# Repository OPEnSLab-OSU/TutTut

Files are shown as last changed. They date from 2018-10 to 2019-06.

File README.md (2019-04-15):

# TutTut
Tut-Tut, the IoT Raindrop Detector, is a project under the domain of the OPEnS (Openly Published Environment Sensing) Lab at Oregon State University. 
Tut-Tut will be able to detect a raindrop of any size, get an idea of the drop's mass from the intensity at which it falls, and detect the frequency of raindrops. 
After Tut-Tut gathers this data, it will be able to wirelessly transmit the information to a central server and communicate it to other IoT devices around Oregon State University.
The detector will periodically wake up to check for rain and will stay awake as long as rain is detected within two minutes. If it does not detect raindrops within two minutes, it will go back to sleep.
As a stretch goal, we will design an online mobile application to which the physical device will transmit information about the raindrops.
If this stretch goal is not met, then the data will be stored in a Google Sheet.

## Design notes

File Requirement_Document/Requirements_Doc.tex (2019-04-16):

%\documentclass[10pt,a4paper]{article}
\documentclass[letterpaper,10pt,draftclsnofoot,onecolumn]{article}
\usepackage[letterpaper, margin=.75in]{geometry}

\usepackage{hyperref}
\usepackage{listings}
\usepackage{wasysym}
\usepackage{graphicx}

\graphicspath{ {./images/}}

\hypersetup{
	colorlinks,
	citecolor=black,
	filecolor=black,
	linkcolor=black,
	urlcolor=black
}

\begin{document}
\begin{titlepage}
\vspace*{\fill}
\begin{center}
{\Large Tut-Tut, The IoT Rain Fall Detector Requirements Document}
\\[0.3cm]

{\large CS 461 - Fall 2018}
\\[0.3cm]

{\large Jonathan Rohr}
\\[0.3cm]

{\large Michael Gillett}
\\[0.3cm]

{\large Shreyans Khunteta}
\\[0.3cm]

{\large October 23, 2018}
\\[1cm]

{\Large Abstract}
\end{center}
Tut-Tut, the IoT Raindrop Detector, is a project under the domain of the OPEnS (Openly Published Environment Sensing) Lab at Oregon State University. Tut-Tut will be able to detect a raindrop of any size, get an idea of the drop's mass from the intensity at which it falls, and detect the frequency of raindrops. After Tut-Tut gathers this data, it will be able to wirelessly transmit the information to a central server and communicate it to other IoT devices around Oregon State University. The detector will periodically wake up to check for rain and will stay awake as long as rain is detected within two minutes. If it does not detect raindrops within two minutes, it will go back to sleep. As a stretch goal, we will design an online mobile application to which the physical device will transmit information about the raindrops. If this stretch goal is not met, then the data will be stored in a Google Sheet.
\vspace*{\fill}
\end{titlepage}

\section{Introduction}
In this document we will be outlining the requirements of Tut-Tut, the Internet of Things (IoT) Rainfall Detector. Requirements are as per requested by Chet Udell and the OPEnS Lab located at Oregon State University.

\subsection{Purpose}
This document intends to guide development of Tut-Tut over the course of 7 months. It will go through changes in the duration of the project as new information makes itself clear.

\begin{enumerate}
    \item \textbf{Draft:}  The first draft is written by the development team after requirements have been outlined by their client. 
    \item \textbf{Proposal:} The drafted document will be passed along to all other parties involved, including the client, OPEnS lab team, and course professors, who will evaluate the requirements outlines and request changes where necessary.
    \item \textbf{Approved:} The document is considered approved when it is accepted by all parties. Following this, the development team can begin implementing their technology using the document as a guide.
\end{enumerate}

\subsection{Target Audience}
This product is designed to accommodate any person(s) who may want to know about rainfall metrics in their area. The sensor will provide real-time information about the relative intensity of the rain based on the impacts of the drops and how frequently they are falling. These metrics could be used by meteorologist as a way to show more detailed information about the rain in the local area. Furthermore, the Tut-Tut Rainfall Detector will link into the OPEnS lab's larger ecosystem of environmental devices and sensors, known as Loom.

\subsection{Project Scope}
%describes the expectations of the product if it were to hit the market, e.g. what must be done to deliver the working product
When the Tut-Tut is finished at the end of the development period, it will be expected to perform three major tasks and one task that will be implemented if there is time. First, it will need to be able to translate vibrations from rainfall using its on-board vibration sensors. Second, it will transmit the collected data to an internet hub where it is subsequently uploaded to Google Sheets in real-time. Third, it must be integrated into the existing OPEnS Lab's ecosystem of sensors and devices called Loom. Finally, if time permits, a browser UI will be used to communicate the Tut-Tut data in an easy to understand way.

\subsection{Business Case for the Product}
%Why do we need this product in the world?
From a business standpoint, this product could deliver an understanding of the rainfall for different areas in the form of a comprehensive map. If the Tut-Tut rainfall detector were to be placed around the country, it could tell you about the type of rain that falls in a given region. Rain on the East Coast might be more of a mist, while the rain in Oregon falls quickly and intense. Tut-Tut would give us the data to show those claims in the form of data it gathers.

\subsection{Overview}
%Summary of the requirements, a general idea
In order to create this device, we will need to program our microcontroller, test vibration sensors, design and 3D print the enclosure, store all code in a github repository, integrate it into Loom, and if possible, create a browser UI as a way to highlight useful information in the spreadsheets.

\section{General Description}
%SECTION TWO, THE REAL DEAL
%Non-technical description, easily read in laymans terms
The IoT raindrop detector will be used to record the amount of rainfall in a particular area. This can be particularly useful in agricultural farming, as this means farmers will know exactly how much rainfall their crops are getting and this way the farmers know how much rainfall they have to provide their crops. 

\subsection{Product Perspective}
%Why are we developing this product?
The thought behind this product's development is that the Loom network managed by Oregon State's OPEnS lab lacks a device that provides more specific details about rainfall. When this product is finished and integrated into their network, the findings might be significant enough to allow Tut-Tut to be available to the public. Even if the data turns out to only be significant to a small population of people, we still will have helped out those individuals, and the Loom network will have a new integration that could inspire similar devices.

\subsection{Product Functions}
%What does it do? Main functions
The main functions of this raindrop detector are that it can detect raindrop impacts, frequency rate and relative intensity of the rainfall based on the raindrop impacts. It also will link up with the network of IoT devices maintained by the OPEnS lab. It will also upload its data to a central server where the information can be viewed in a Google Sheet. It will need to go to sleep while it is not raining so that the battery does not drain.

\subsection{End User Characteristics}
%What would someone using the final product expect from it? Who would that person be? Do they need a technical background or can they use it right away with no prior knowledge of its development?
If we develop the mobile application (which is our stretch goal), the end user can be anyone capable of using the interface. We plan to have a user-friendly interface where anyone can use the application to see the performance metrics of the IoT device.
\newline
If we don't meet the stretch goal, the end user will be anyone able to use the Loom network of IoT devices around Oregon State. This project will be then used next year for another Capstone team to build off of.

\subsection{Constraints}
%Any constraints that might get in the way of development?
One of the biggest constraints of the project is time. All the members of this team are seniors at Oregon State. This is a project we are doing on the side after our classes and jobs, so we have to cut time out of our schedules to work on it. We have created a Standards document which we have all agreed to to deal with this problem in advance.
\newline
But more than that a constraint is Professor Udell's time. He is extremely busy so if we have questions, getting a meeting can be difficult. We have set up a meeting at 10 am every Thursday to circumvent this problem as well.
\newline
Another constraint is equipment. We will be using OPEnS lab equipment for this entire project. We are also totally reliant on them for everything so if some equipment breaks or proves ineffective, we will wait for the lab to get us new equipment.
\newline
Another constraint is expertise. We're students who are doing a project of this magnitude for the first time. We will be learning a lot during this experience but there is absolutely going to be a learning curve. It will take time for us to get up to speed.

\subsection{Assumptions and Dependencies}
%Dependencies (internet connection within range, battery or plug, etc) Assumptions (End User skills or prior knowledge)
Using this product effectively will require an internet connection and a power source. The Feather M0 microcontroller comes equipped with a Wi-Fi card, so anywhere on the university should be suitable enough for Tut-Tut. Using the device anywhere else must have a Wi-Fi signal within range. Another dependency is the power source. Because Tut-Tut is intended to be moved around, Tut-Tut should run on a battery. The type of battery we will use is undetermined, and will be figured out in the testing phase. Users should need no prior knowledge to configure and set up Tut-Tut.

\section{Specific Requirements}
This section of the document lists specific requirements for Tut-Tut. Requirements will be divided into three sections:
\begin{enumerate}
    \item \textbf{User Requirements: } These are requirements written from the point of view of the end users who will be using the product.
    \item \textbf{System Requirements: } These are the detailed specifications that the product's internal hardware will need to be capable of doing.
    \item \textbf{Interface Requirements: } These are the requirements about how the information gathered by the device will be presented 
\end{enumerate}

\subsection{User Requirements}
%Minimal, since the information will be understood by everyone
The user will, provided our stretch goal is met, be anyone. The information will be easily accessible and understandable. Even if our stretch goal isn't met, we will still display our data gathered in a Google Sheet that should be able to be understood by anyone.

\subsection{System Requirements}
%2x2 inch sensor capable of detecting even the most minute amounts of rain, wifi or network capabilities, able to be integrated with mesh network, waterproof
The system will be a 2x2 inch weather resistant sensing area capable of detecting even the most minute amounts of rain. It will have wi-fi or network capabilities and we will be able to integrate it easily with the IoT mesh network around the university. It will be able to detect the raindrop impacts, the frequency at which rain is falling, and the intensity at which it hits the detector. The device will also need to go to sleep while it is not raining to conserve battery. It will awaken when it can detect rain falling and will continue gathering data.

\subsection{Interface Requirements}
%needs to be accessible and give accurate or clear information. Perhaps in the form of a generated map visual, or a twitter bot.
The interface for the mobile application, if the stretch goal isn't met, will just be an Excel spreadsheet with all the data cleanly labelled. If the stretch goal is met, it will be a mobile application that can easily be navigated. The specifics of the application's appearance will be worked out, but it will be easy to look at and trivial for an inexperienced user to find all the information they are looking for.

\section{Gantt Chart}
%Chart outlining the timeline of this project. Term one is design, Term two is bulding, and Term 3 is testing. That's my only information


\newline

\bibliography{myref}
\bibliographystyle{ieeetr}

\end{document}t}

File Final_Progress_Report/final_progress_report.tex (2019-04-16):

%\documentclass[10pt,a4paper]{article}
\documentclass[letterpaper,10pt,draftclsnofoot,onecolumn]{article}
\usepackage[letterpaper, margin=.75in]{geometry}

\usepackage{hyperref}
\usepackage{listings}
\usepackage{wasysym}
\usepackage{graphicx}
\usepackage{float}

\graphicspath{ {./images/}}

\hypersetup{
	colorlinks,
	citecolor=black,
	filecolor=black,
	linkcolor=black,
	urlcolor=black
}

\input{arduinoLanguage.tex}

\begin{document}
\begin{titlepage}
\vspace*{\fill}
\begin{center}
{\Large Tut-Tut, The IoT Rainfall Detector Progress Report}
\\[0.3cm]

{\large Team 21}
\\[0.3cm]

{\large CS 461 - Fall 2018}
\\[0.3cm]

{\large Jonathan Rohr,}
{\large Shreyans Khunteta,}
{\large Michael Gillett}
\\[0.3cm]

{\large February 21st, 2019}
\\[1cm]

{\Large Abstract}
\end{center}

Tut-Tut, the IoT Raindrop Detector, is a project under the domain of the OPEnS (Openly Published Environment Sensing) Lab at Oregon State University. Tut-Tut will be able to detect a drop of any size, get an idea of the raindrop mass from the intensity at which it falls, and detect the frequency of raindrops. After Tut-Tut gathers this data, it will be able to wirelessly transmit the information to a central server and store it in a database. This document will explore multiple possible technologies that can be used to gather, transmit, and store our data.
\vspace*{\fill}
\end{titlepage}

\section{Project Purposes and Goals}
The purpose of Tut-Tut is to provide metrics for understanding the intensity of rainfall as it is happening. We plan on using our sensor to measure how forceful the impact of the raindrops are, and the microcontroller's built-in timer to record the duration between those drops.
\newline
With these two parameters, we will place each recorded drop on a scale between 0 and 100, 0 being no rain at all and 100 being torrential downpour, and provide a key with ranges describing the rain in more familiar terms. For example: 0-15 would represent a mist, 15-30 would represent a light rain (jacket recommended), 30-45 would represent a medium rain (umbrella recommended), all the way up to cataclysmic conditions. A rating of 100 should not be reasonably attainable on our scale, so that we can represent any recorded value somewhere on the spectrum. 
\newline
We were hoping to introduce a browser UI system to represent this data in a colorful map or Twitter feed, but this will likely be cut out due to time constraints. That browser UI will be left to a future Capstone team. Such a browser UI could potentially have appealing visuals along with the OSU logo that will render the information much easier to read. However, at the moment, we will just publish the results to a Google Sheets using PushingBox.
\newline
The ultimate end goal use of Tut-Tut will be to, for example, put in farmer's fields. Farmers will be able to see how much rain their crops are getting in specific areas and thus know exactly how much water they should give their crops. This will greatly aid in water conservation which has become a moral and practical necessity as the effects of climate change worsen.

\section{Current Progress}
We have chosen the MEMS sensor due to how sensitive it is relative to the accelerometer and the piezoelectric transducer. In addition we were able to build a quite functional rig that can detect raindrops and then have them neatly slide off the disk. Our MEMS sensor can detect the force of the impacts and we have code that gives us the average amplitude for a specific duration of time. That same duration is used to calculate the frequency that raindrops impact the sensing area. Our microcontroller enters low-power mode when the sensor hasn't detected a drop in one minute. A drop hitting the sensing area will trigger an interrupt that will wake up the microcontroller so data can be gathered again. Our data gets sent to a Google Sheet every two minutes using a Pushing Box API Scenario. Essentially, the data is used as URL arguments for a get request to Google Sheets. A script in our Google Sheet will recognize the format of the request and will add the data to the sheet.
\newline
\newline
We made some 3D prints of disks and our casing for the electronic components by using a software called Autodesk Fusion360 after an unsuccessful attempt in using AutoCAD Architecture. After realizing that AutoCAD Architecture was a bit of a nightmare to use, we switched over to Autodesk Fusion360 on the advice of Professor Chet Udell. We learned how to use Autodesk Netfabb to check the mesh to make sure there were no errors in it, and then we used Cura Lulzbot to compile our meshes into a file, which we save to an SD card. This SD card is then put in the OPEnS Lab's TAZ 3D printer, where we select it and begin printing our designs.

\section{What is Left To Do}
We still have a few tasks ahead of us before Tut-Tut will function as intended. First, we plan to maybe 3D print another casing that will hold all the components we need- breadboard, microcontroller, battery, sensor, and all connecting wires. This casing would have a sensing area slanted at a 35-45 degree angle. We want to try the angled model to see if the sensing capability is different because in our lab tests we had a problem with water collecting on the surface of the level sensor. After we test both of our casings, we will choose the one that records data most accurately. Next, we need to finish setting up our microcontroller to send its collected data to our designated spreadsheet using the PushingBox API. This tool allows us to upload data to the specified document in real-time, so we can record and view the results as they are happening. We have the base code done, but rigorous testing needs to be completed to ensure that it will send data while in the field. We also need to connect our microcontroller to a battery and perform tests to make sure that all of our code functions properly when it is disconnected from a laptop. Once we have chosen a model, we will make adjustments as necessary to waterproof the casing and make the microUSB input accessible for charging the battery and making changes to the code. If we find ourselves with extra time, we could attempt to make a very simple UI for conveying the collected data. However, time has been one of our biggest constraints this term, so this task remains a stretch goal.
\newline
\newline
On a non-technical note, we still have the entirety of the Spring term left, and the most important part of that term will be appearing at Oregon State's Engineering Expo to show our finished product.

\section{Problems with Progress}
The main problem with our progress has simply been time. We're all students with several other classes as well as jobs. In addition, our advisor, Professor Chet Udell, is a very busy man managing several other Capstone projects, so we can't necessarily meet with him every week. In addition we had some difficulties scheduling our TA meetings earlier in the term. We would meet in the OPEnS Lab and get so immersed in building our rig that we would simply forget to go to our meetings at 1 pm on Mondays. We have moved our meeting time now to 12:45 pm on Wednesdays and have been much more consistent about being able to attend them. Another factor that has impeded our progress has been our inexperience with electrical hardware components and using a 3D printer. A good portion of our time this term has been spent doing self-research on those topics, and asking for help in the OPEnS lab if that proves ineffective. We have learned a great amount of skills that could definitely help us later on, such as creating mesh models and wiring a microcontroller and a sensor to a breadboard.

\section{Code}

\lstinputlisting[language=Arduino, firstline=19, lastline=48]{piezo_vibration_sensor.ino}
\vspace{4mm}
First we include the config.h and loom\_preamble.h files to make sure our code is connected to the large loom library. This will give us access to hundreds of functions for use in our code. We then define our global variables that we will use throughout our functions. Variables of note are: PIEZO\_PIN which is the pin connected to our sensor, duration which is the specified time in seconds that we want our timer to run for, and the average, frequency, and intensity variables that will hold our data.

\vspace{4mm}

\lstinputlisting[language=Arduino, firstline=53, lastline=62]{piezo_vibration_sensor.ino}
\vspace{4mm}
Next we have our setup function which calls all relevant setup functions through the Loom\_begin function. For example, our board is connected to WIFI here.

\vspace{4mm}

\lstinputlisting[language=Arduino, firstline=67, lastline=82]{piezo_vibration_sensor.ino}
\vspace{4mm}
Our Main Loop sets up the Bundle we will use to send data to the Pushing Box functions. It then calls the gather\_data function which contains all of the data collection code. That data is then appended to the bundle and the bundle is sent to the Pushing Box functions which constructs a URL using the data key-values and send it as a get request to our Google Sheet. A simple script in the Google Sheet interpolates the URL arguments and adds the data to the Spreadsheet.

\vspace{4mm}

\lstinputlisting[language=Arduino, firstline=261, lastline=323]{piezo_vibration_sensor.ino}
\vspace{4mm}
Our gather\_data function contains our data collection code. We start by checking to see if it is raining. If it is not, then the microcontroller will go to sleep. It will awaken when the sensor triggers an interrupt (from a rain drop). If it is raining, then the rest of our code is run. Our sleep code is not fully operational and requires further testing.
\newline
\newline
We continue by setting the timer if loopReset = true. We then call the call\_timer function to see if the timer is running or if it has ended. If it is still going, then we read the output from PIEZO\_PIN and store that value into an array. The delay is to prevent excess readings from being recorded.
\newline
\newline
If the timer has stopped, then we add together all of the data values and divide that by the total number of values to get the average. We take the total number of values and divide it by the duration to get the frequency. To find the intensity, we compare the average to set ranges to determine how hard the rain was falling. 

\vspace{4mm}

\lstinputlisting[language=Arduino, firstline=326, lastline=336]{piezo_vibration_sensor.ino}
\vspace{4mm}
This is our call\_timer function where we check to see if the timer has ended. Two integers are passed into the function: start and duration. The start value is usually 0 if we only have one timer set, but if we had additional timers then we would tell the function when the start of those timers would be. For example, if timer 1 has a start of 0 and a duration of 60, then timer 2 would have a start of 61 so there is no overlap. The duration value is how long in seconds that we want the timer to be active for. In our case, we will have the duration set to 120 because we want the data collection intervals to be two minutes long. If the timer value (think of it as current time elapsed) is in the range of the startTime and endTime values, then the timer is still active and it returns true. If it is out of that range, then the timer has ended and it returns false.

\vspace{4mm}
\section{Images}

\begin{figure}[H]
\centering
    
    \caption{The testing setup for our sensor and prototype sensing area.}
\end{figure}

\vspace{4mm}

\begin{figure}[H]
\centering
    
    \caption{The wiring of our sensor to our microcontroller.}
\end{figure}

\vspace{4mm}

\begin{figure}[H]
\centering
    
    \caption{3D printed enclosure and sensor disk (right) and our Adafruit Feather M0, battery, and breadboard (left).}
\end{figure}

\bibliography{myrefA}
\bibliographystyle{ieeetr}

\end{document}

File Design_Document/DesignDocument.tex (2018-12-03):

%\documentclass[10pt,a4paper]{article}
\documentclass[letterpaper,10pt,draftclsnofoot,onecolumn]{article}
\usepackage[letterpaper, margin=.75in]{geometry}

\usepackage{hyperref}
\usepackage{listings}
\usepackage{wasysym}
\usepackage{graphicx}

\hypersetup{
	colorlinks,
	citecolor=black,
	filecolor=black,
	linkcolor=black,
	urlcolor=black
}

\begin{document}
\begin{titlepage}
\vspace*{\fill}
\begin{center}
{\Large Tut-Tut, The IoT Rain Fall Detector Design Document}
\\[0.3cm]

{\large Team 21}
\\[0.3cm]

{\large CS 461 - Fall 2018}
\\[0.3cm]

{\large Michael Gillett, Casing and Microcontroller Lead}
\\[0.3cm]
{\large Jonathan Rohr, Data Collection and Management Lead}
\\[0.3cm]
{\large Shreyans Khunteta, UI Lead}
\\[0.3cm]

{\large November 26, 2018}
\\[1cm]

{\Large \textbf{Abstract}}
\end{center}
Tut-Tut, the IoT Raindrop Detector, is a project under the domain of the OPEnS (Openly Published Environment Sensing) Lab at Oregon State University. Tut-Tut will be able to detect a drop of any size, get an idea of the raindrop mass from the intensity at which it falls, and detect the frequency of raindrops. After Tut-Tut gathers this data, it will be able to wirelessly transmit the information to a central server and communicate it to other IoT devices around Oregon State University. The detector will have a 2 cm by 2 cm area it can sense rain in, will wake up with a single raindrop, and will stay awake as long as more rain is detected within a minute. In addition to the physical device, we will also design a browser UI to make the gathered data more readable.
\vspace*{\fill}
\end{titlepage}

\begin{center}
\section*{Glossary}
\end{center}

\quad \newline
\textbf{OPEnS Lab:} Openly Published Environmental Sensing Lab. Located at Oregon State University, this lab's goal is to develop environmental sensing devices and do research on their findings.
\newline
\newline
\textbf{CAD:} Computer-Aided Design. CAD is not a single program, but a technique used by many programs to design and simulate 3D objects that will be used in production.
\newline
\newline
\textbf{IDE:} Integrated Development Environment. Usually refers to the program being used to write and test the coded sections of the project.
\newline
\newline
\textbf{IoT:} Internet of Things. Used to describe a system made up of interconnected devices that form a network.
\newline
\newline
\textbf{Piezo Sensor:} Piezoelectric sensor. A device that uses the piezoelectric effect to measure changes in force by converting them to an electrical charge.
\newline
\newline
\textbf{MEMS Piezo Vibration Sensor:} Microelectromechanical systems sensor. Uses the piezoelectric effect to measure vibrations, but the sensor is small and its components are near microscopic.
\newline
\newline
\textbf{Accelerometer:} A device that measures vibrations from acceleration forces using electromechanical technology. It measures forces as voltages and then translates those voltages into vibration measurements.
\newline
\newline
\textbf{M0 Feather Microcontroller}: The M0 Feather is a microcontroller from Adafruit. It is thin, light and the centerpiece of our project. It will be handling all the computing for Tut-Tut.

\pagebreak

\tableofcontents
\pagebreak

\section{Introduction}
\subsection{Purpose}
This document will outline the design specifications referenced in each of the group members' Tech Reviews. We will discuss the design of the pieces, technologies, methods, and other parts that will be included in the final product. The final product may differ slightly from the specifications in this document, but it should act as a roadmap moving forward.

\subsection{Scope}
When the Tut-Tut reaches the end of its development, it will be expected to perform three major tasks and one task that will be implemented if there is time. First, it will need to be able to translate vibrations from rainfall into a voltage using its onboard vibration sensors. Second, it will transmit the collected data to the OPEnS Lab's Dropbox where it is subsequently stored into a spreadsheet in real-time. Third, it must be integrated into their existing ecosystem of sensors, Loom. Finally, if time permits, a browser UI will be used to communicate the Tut-Tut data in an easy to understand way.

\subsection{Document Overview}
First, Michael details the code we will use in our Microcontroller and describes the protective casing that will encase all components of our project. Second, Jonathan describes how we will be collecting rainfall data with sensors and how that data will be sent to our online database. Finally, Shreyans outlines what our stretch goal website would look like. The group members will be primarily responsible for all the technologies in their respective sections for the remaining time frame of the entire project.

\section{System Overview}
This product is designed to accommodate any person(s) who may want to know about rainfall metrics in their area. The sensor will provide real-time information about the size/mass of the raindrops, how frequently they are falling, and the intensity of the rainfall. These metrics could be used by meteorologist as a way to show more detailed information about the rain in the local area. They could also be used by farmers to better take care of their crop fields. Furthermore, the Tut-Tut Rainfall Detector will link into the OPEnS lab's larger ecosystem of environmental devices and sensors, known as Loom. The data Tut-Tut collects will be stored in a Google Sheets database for analysis.

\section{System Architecture}

\subsection{Code Design}
This section outlines the flow of the code flashed onto the microcontroller. 
\\
\\
We will be using an Adafruit Feather M0 microcontroller with Wi-Fi capability. The code that we will use can be divided into two phases: Initialization and Loop. The initialization section will set up all the necessary pins as soon as the device is booted, such as the LED and the analog pin used by the sensor. The looping portion of the code will run continuously, record the necessary data metrics, and upload them to the central server.
\\
\\
Once we test the sensor pieces and can record an accurate output of voltage (about a 1\% error), we will have an accurate threshold of voltage that will constitute a raindrop. In the main loop, we will first check the state of the sensor. If the voltage read is above our derived value, the program flow will enter an if-statement that will take care of the uploading. For good measure, we will have a delay function at the end of the loop to avoid overloading the buffer and losing our data.\cite{Knock} 

\subsection{Casing Design}
We have not yet done a model of Tut-Tut, but we do have a few expectations of what it should contain. First, we want the final product to be portable and able to be moved from place to place. To accomplish this we will need room in the casing for a battery, our microcontroller, and the sensor. Since the device will be out in rain, the casing containing the electronics will need to be weatherproof. The shape of Tut-Tut will likely be a 2 cm by 2 cm disk-shaped area on the top for raindrops to fall on, with a heavier base containing the hardware. Figure 1 shows what Tut-Tut might look like at the end of production given these specifications.
\newline

\begin{center}
Figure 1: A basic drawing of what Tut-Tut will resemble when complete

\end{center}

\subsection{Design Rationale}
Each of the pieces of Tut-Tut had to be chosen specifically regarding the purpose of the final product. Trade-offs were (or will be) made on both the sensor and microcontroller pieces. For the microcontroller, we had the option of a basic board, one with Wi-Fi capability, and one with Long-Range Radio capability. We chose the Wi-Fi model because of the constant connection and reliable transfers of data. The sensors available to us are a piezo, a MEMS, and an accelerometer. These devices are all similar in usage and will only change the specific design of the 3D-printed casing depending on which is chosen.

\section{Data Design}

\subsection{Data Collection}
Tut-Tut will use sensors to register vibrations from raindrops. Using data gathered from the sensors, it will determine the size, density, mass, and frequency rate of these raindrops as they fall. We will be using the Piezo Vibration Sensor and the Piezo Element to accomplish these tasks. 
\\
\\
The Piezo Vibration Sensor is a MEMS sensor which uses the piezoelectric effect to detect vibrations. It has dimensions of around 1 cm wide and 2 cm long. It has a high voltage sensitivity of 1 V/g at its baseline and 6 V/g at its resonance. The sensor generates AC and voltage when the thin film gyrates. These voltages can help determine the impact velocity and mass of the raindrops.
\\
\\
The Piezo Element is a basic sensor that also uses the piezoelectric effect to detech vibrations. Raindrops impacting the flat sensor will generate voltage that will be used to determine their impact velocity and mass. The two sensors perform the same task in different ways, so they each will be tested to determine which one will work best for Tut-Tut.

\subsection{Data Management}
Tut-Tut will be gathering data in the field. This means no one will be around to monitor its results immediately. All of the data that is collected by the sensors above will have to be sent wirelessly, in real-time, to an internet hub. We will use the PushingBox to Google Sheet Pipeline that has already been discovered by the OPEnSLab.\cite{PushingBox} As our Arduino Board gathers data from the sensors, it will make GET requests to a PushingBox Scenario using the data to be sent as URL arguments. The PushingBox Scenario formats the data and sends it as URL arguments in its own GET request to the Google Sheet. The Google Sheet will then parse through and display the data. PushingBox currently only supports 1000 requests per day per user. This means that Tut-Tut will only be able to send a string of data once every two minutes.

\section{Human Interface Design}
Currently our scope for the UI is limited. All the information and relevant performance metrics will appear as an Excel spreadsheet you can access through a website link. However, our stretch goal is to create a fully functioning user interface that the user can navigate. This fully functional user interface will be on a website that looks fairly similar to the OPEnS lab website (http://www.open-sensing.org/). 
\newline

\begin{center}
Figure 2: The current OPEnS Lab website. Tut-Tut's website will resemble this in aesthetic.\cite{OPEnSLab}

\end{center}

\subsection{Overview of User Interface}
This user interface will be built with programming languages such as HTML, CSS and JavaScript. The user interface design is still in progress and it is important to stress that this is a stretch goal. However, we want the final appearance of it to be visually appealing and engaging, and to be be usable and understandable by any educated user, and not just the OPEnS lab staff and students.

\subsection{Screen Images}
The images on the screen will be pictures of OPEnS staff and OPEnS lab projects, such as Tut-Tut itself. It will remain tasteful and aesthetically pleasing, and will incorporate Oregon State logos as well. We will have it try to remain the OPEnS lab webpages themselves.

\subsection{Screen Objects and Actions}
We may implement some minor transitions between pages to make the site look more appealing to the user. However we are not going to use JavaScript effects for the sake of JavaScript effects. We want every transition we do to be for the ultimate comfort and ease of the user. Our design for this will flesh out as the project goes forward, as this is still our stretch goal.

\pagebreak

\section{Conclusion}
This document will generally outline the remainder of Tut-Tut's production and give us a road map in which to reference as needed. First, the code will constantly loop checking for forces read from the Piezo above our calculated threshold, and take appropriate action when an exerted force does cross it. Next, we will have all of our hardware components contained in a waterproof shell that is bottom-heavy with a 2x2 cm disk-shaped surface area to measure the rain drops as they hit. The resulting voltages will be translated into meaningful data and sent through the PushingBox to Google Sheet Pipeline. Finally, if time permits, we will create a UI based off the OPEnS Lab website. It will be easily navigable by any user and will have performance metrics that Tut-Tut will be tracking (raindrop size, intensity and frequency rate). If we are unable to meet this stretch goal, the UI will simply be a Google Sheets document with all the relevant performance metrics.

\pagebreak
\bibliography{reference}
\bibliographystyle{ieeetr}

\end{document}

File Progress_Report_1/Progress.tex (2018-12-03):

%\documentclass[10pt,a4paper]{article}
\documentclass[letterpaper,10pt,draftclsnofoot,onecolumn]{article}
\usepackage[letterpaper, margin=.75in]{geometry}

\usepackage{hyperref}
\usepackage{listings}
\usepackage{wasysym}
\usepackage{graphicx}

\hypersetup{
	colorlinks,
	citecolor=black,
	filecolor=black,
	linkcolor=black,
	urlcolor=black
}

\begin{document}
\begin{titlepage}
\vspace*{\fill}
\begin{center}
{\Large Tut-Tut, The IoT Rain Fall Detector Design Document}
\\[0.3cm]

{\large Team 21}
\\[0.3cm]

{\large CS 461 - Fall 2018}
\\[0.3cm]

{\large Michael Gillett, Casing and Microcontroller Lead}
\\[0.3cm]
{\large Jonathan Rohr, Data Collection and Management Lead}
\\[0.3cm]
{\large Shreyans Khunteta, UI Lead}
\\[0.3cm]

{\large November 26, 2018}
\\[1cm]

{\Large \textbf{Abstract}}
\end{center}
 Tut-Tut, the IoT Raindrop Detector, is a project under the domain of the OPEnS (Openly Published Environment Sensing) Lab at Oregon State University. Tut-Tut will be able to detect a drop of any size, get an idea of the raindrop mass from the intensity at which it falls, and detect the frequency of raindrops. After Tut-Tut gathers this data, it will be able to wirelessly transmit the information to a central server and communicate it to other IoT devices around Oregon State University. The detector will wake up with a single raindrop and will stay awake as long as rain is detected within a minute. If it does not detect raindrops within a minute, it will go back to sleep. In addition to the physical device, we will also design an online mobile application to which the physical device will transmit information about the raindrops.
\vspace*{\fill}
\end{titlepage}

\section{Introduction}
This document will go into depth on the progress made in Fall Term regarding our project. Our device is known as Tut-Tut, the IoT (Internet of Things) Rainfall Detector, and will serve the OPEnS Lab's ecosystem of environmental sensing devices which they call Loom. Tut-Tut will measure the rainfall by reading the mechanical stress of drops hitting its built-in sensor, and relay it to their server using PushingBox technology. The metrics Tut-Tut wants to know are how hard the drops hit the device, and how often a rain drop strikes it. These values will be continually updated into an easily accessible spreadsheet. In the document, we will linearly outline all of our progress so far, discuss all the problems encountered this term, include any plans we have to fix those problems next term in a retrospective table.

\section{Current Progress \& Problems}
This term we began work on Tut-Tut in week four, when we were assigned the project. We met with Professor Chet Udell that week and were given an Adafruit Feather M0 microcontroller to work with. Professor Udell told us to have a blinking microcontroller by the next week. We were unable to run any Arduino sketches on our microcontroller and thought initially that it was a problem with our drivers, as it wasn't working on any of our computers. We had a wide range of laptops and operating systems between us, so that was baffling. We brought it into the OPEnS Lab and the staff discovered the microcontroller we had been given was faulty. We exchanged it for a new one that worked much better and were able to show the microcontroller blinking to Professor Udell and the OPEnS staff minutes after being given an operational microcontroller.
\\
\\
After this, we were told the names of the sensors and transducers we had to acquire. We were able to order them online and have them delivered to Michael Gillett's Corvallis home. However, Michael was in a horrific car accident on his way to Portland the weekend before Thanksgiving and was stranded there for 8 days. We were unable to open his mailbox and get our equipment, so that delayed us by a week and a half.
\\
\\
We've also had some difficulty in being able to meet with Professor Udell due to his busy schedule. We have a set meeting time on Thursdays, but because we started this project midway through the term and because some meetings have to be cancelled abruptly due to Professor Udell's busy schedule, we haven't had as much time with him as we would like.
\\
\\
However, we were able to produce a Problem Statement, Requirements document, three detailed Tech Reviews, a Design Document and weekly progress reports since week four. This will help us in setting goals and guidelines for the assignment going forward. 
\\
\\
The Problem Statement was used to develop a working definition of the problem we're solving. Normal rainfall collectors do not provide enough information for the needs of the OPEnS Lab. Our client wants a small, portable, disc-shaped device that can detect and provide detailed information about falling rain in real-time. Information includes rainfall rate, intensity, and density. We also defined Tut-Tut's eventual goals and use cases for them.
\\
\\
The Requirements document was used to define Tut-Tut's scope and our eventual goals for it. This was the "What" document that we used to explain our target audience, our project scope, our business case, user characteristics, assumptions/dependencies and our constraints. The system will be a 2x2 inch waterproof sensor capable of detecting even the most minute amounts of rain. It will have wi-fi or network capabilities and we will be able to integrate it easily with the IoT mesh network around the university. It will be able to detect the size of a raindrop, the frequency at which rain is falling, and the intensity at which it hits the detector.
\\
\\
During the Tech Review, each of us submitted an individual tech review for technologies we are taking responsibility for: data collection and management, microcontroller and 3D printed shell, and coding tools. During these documents we identified the tools we would need to accomplish the task ahead of us, and we explored different alternative methods to implement these different technologies. For example, when listing different usable technologies for the Shell, Michael listed three different potential technologies - Inventor, Onshape and AutoCAD. After exploring each in detail, he explained why we would be using AutoCAD ultimately.
\\
\\
Finally, we wrote the Design Document. In the Design document we described our timeline and explained the design of our project in all respects - the Code Design, the Casing Design, our Data Design (how we would collect and manage data), and our Human Interface Design.  We drew upon our previous Tech Review and Requirements documents to properly write this Design Document.

\section{Pieces of code}
\begin{lstlisting}[language=C]
/*
  Knock Sensor

  This sketch reads a piezo element to detect a knocking sound.
  It reads an analog pin and compares the result to a set threshold.
  If the result is greater than the threshold, it writes "knock" to the serial
  port, and toggles the LED on pin 13.

  This example code is in the public domain.

  http://www.arduino.cc/en/Tutorial/Knock
*/

// these constants won't change:
const int ledPin = 13;      // LED connected to digital pin 13
const int knockSensor = A0; // the piezo is connected to analog pin 0
const int threshold = 100;  // threshold value to decide when the detected sound is a knock or not

// these variables will change:
int sensorReading = 0;      // variable to store the value read from the sensor pin
int ledState = LOW;         // variable used to store the last LED status, to toggle the light
\\
void setup() {\\
  pinMode(ledPin, OUTPUT); // declare the ledPin as as OUTPUT
  Serial.begin(9600);       // use the serial port
}

void loop() {
  // read the sensor and store it in the variable sensorReading:
  sensorReading = analogRead(knockSensor);

  // if the sensor reading is greater than the threshold:
  if (sensorReading >= threshold) {
    // toggle the status of the ledPin:
    ledState = !ledState;
    // update the LED pin itself:
    digitalWrite(ledPin, ledState);
    // send the string "Knock!" back to the computer, followed by newline
    Serial.println("Knock!");
  }
  delay(100);  // delay to avoid overloading the serial port buffer
}
\end{lstlisting}

Because of the fact that we have not been able to test our sensors, we have not written any code for the microcontroller yet. We plan to use this example as a basis for Tut-Tut. The "knock" will be drops of water on the piezoelectric sensor, and the Serial.println function will be the PushingBox API uploading the data to our central server. We also have received a code example using interrupts which could prove useful in letting Tut-Tut sleep when no rain is falling. By having a drop generate an interrupt to wake up the device instead of constantly being active, we could save battery.

\section*{Basic Sketch}
\begin{center}
Figure 1: A basic drawing of what Tut-Tut will resemble when complete

\end{center}

\section{Retrospective}

\begin{center}
\begin{tabular}{ |p{0.3\linewidth}|p{0.3\linewidth}|p{0.3\linewidth}| }
\hline
\multicolumn{3}{|c|}{Retrospective Table} \\
\hline
Positives & Deltas & Actions \\
\hline
Team met semi-often and meetings were effective. & 
Frequency of meetings needs to be increased. & 
We will schedule at least two meetings a week. \\
 & & \\
Team communication was frequent through texting. & 
Another communication medium needs to be explored to improve our accessibility to each other. & 
We will create a Discord server so that we can communicate using our phones and our computers. \\
 & & \\
Each team member participated in writing assignments. & 
Writing assignments need to be started multiple days prior to the due date. & 
We will look at all writing assignment due dates and plan ahead to start them 2-3 days beforehand so that have enough time to complete them. \\
 & & \\
Our client is on campus. & 
Since our client is very busy, more of an effort needs to made to communicate and schedule meetings with him.  & 
We will use BaseCamp to send him questions and requests. If he does no answer, then we will assign him tasks so that he knows what he needs to do for us.  \\
 & & \\
We have access to the OPEnS Lab on campus to test our sensors and 3D Print components. & 
We require weekend or after-hour access in order effectively complete our project. & 
We will talk with our client to work out ways we can have more access to the OPEnS Lab.  \\
 & & \\
All of the parts and components we need to complete the project are in our possession. & 
We will utilize the parts to start sensing vibrations and displaying data. & 
We will connect the sensors to the microcontroller and use code to detect taps on the sensors. We will then start testing it with water and pipettes. \\
 & & \\
\hline
\end{tabular}
\end{center}

\pagebreak

\bibliography{reference}
\bibliographystyle{ieeetr}

\end{document}

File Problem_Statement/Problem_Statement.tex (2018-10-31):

\documentclass[letterpaper,10pt]{article}
\usepackage[letterpaper, margin=.75in]{geometry}

\usepackage{hyperref}
\usepackage{listings}
\usepackage{wasysym}
\usepackage{graphicx}

\hypersetup{
	colorlinks,
	citecolor=black,
	filecolor=black,
	linkcolor=black,
	urlcolor=black
}

\begin{document}
\begin{titlepage}
\vspace*{\fill}
\begin{center}
{\Large Tut-Tut, The IoT Rain Fall Detector}
\\[0.3cm]

{\large CS 461}
\\[0.3cm]

{\large Fall 2018}
\\[0.3cm]

{\large Michael Gillett}
\\[0.1cm]

\large {October 11, 2018}

\begin{abstract}
\normalsize
Tut-Tut, the IoT Raindrop Detector, is a project under the domain of the OPEnS (Openly Published Environment Sensing) Lab at Oregon State University. Tut-Tut will be able to detect a raindrop of any size, get an idea of the drop's mass from the intensity at which it falls, and detect the frequency of raindrops. After Tut-Tut gathers this data, it will be able to wirelessly transmit the information to a central server and communicate it to other IoT devices around Oregon State University.
\newline
The detector will wake up with a single raindrop and will stay awake as long as rain is detected within a minute. If it does not detect raindrops within a minute, it will go back to sleep.
In addition to the physical device, we will also design an online mobile application to which the physical device will transmit information about the raindrops.
\end{abstract}   
\end{center}
\vspace*{\fill}
\end{titlepage}

\section{Problem Statement}
The OPEnS Lab at Oregon State University is dedicated to developing technology that helps better our understanding of the world around us. They develop tools that can, for example, detect the water content of soil across a patch of farm land, and give real-time updates about their conditions. Say the field is getting an overload of water in one particular area: their technology could hook up to the sprinkler system and water only the sections of the field with water content below a certain threshold.
\newline
\newline
Say you want information about the water flowing in a river, creek, or stream: they have an artificial rock designed with several sensors to be placed in the running water and give information about the flow, temperature, or other details. These are just some of the components of their ever-growing neural network. However, there is still more that can be done. For a long time, we've used rainfall collectors that can tell us the volume of the rain that has precipitated in an area over a given period of time, but sometimes that just doesn't tell us enough. The problem that our client, Professor Udell, outlined for us is that we need some sort of disc-shaped sensory device that can detect and provide detailed information about the falling rain in real-time. 
\newline

\section{Problem Solution}
The solution to the problem of limited data on rainfall is to create Tut-Tut, the IoT Raindrop Detector. Tut-Tut will integrate with the mesh network of IoT devices around the university, and they will provide information to a central server. On this central server, there will be an excel spreadsheet containing all of the most recent data gathered by Tut-Tut. This excel spreadsheet will most likely have raw data, as well as row/column based functions to extract more interesting or presentable data. The server will then feed that information to a mobile application programmed by our team, and this application will display important data on metrics such as raindrop size, rainfall intensity and rainfall rate. This application will allow for real-time monitoring of rainfall patterns in the area. Having this information could allow for farmers to know precisely how much rain their crops are getting, so that they can more precisely measure how much they have to water their crops. This could also allow for much more ideal water conservation methods. 
\newline
\newline
The idea behind most of the OPEnS labs' technology is for it to be able to adapt to new environments without being drastically reconfigured. Their soil moisture sensor can be moved from place to place without raising an error, and their land-based robot can navigate an unknown environment and still know about its position and distance covered. It goes without saying that Tut-Tut should be able to operate in the same manner. It shouldn't matter if we move the device a few feet to the left or even relocate it all the way to the opposite side of campus. As long as we can connect to the server to upload the necessary data, Tut-Tut should continue to operate as normal.
\newline
\newline
In our device, which we will fully design and 3D print at the OPEnS lab, we wanna have a flat, circular sensor approximately 4 inches in diameter that can detect and measure miniscule hits from the rain. The Mechanical Energy produced by the hits is converted into into voltage for our microcontroller. The materials available to create this device are a piezo, a MEMS, or an accelerometer. These all have nearly the same functionality, but we will conduct tests on all 3 of them to see which fits our needs best. The flat sensor will be hooked up to a Feather m0 microcontroller that we will program using Arduino IDE. The microcontroller will be how we incorporate the readings and data manipulation we want, and also how we relay that information to the remote server.
\newline
\newline
\section{Performance Metrics}
This project will be defined as complete when it can:
\begin{enumerate}
    \item Detect a raindrop. The detector will wake up with a single raindrop and will stay awake as long as rain is detected within a minute. If it does not detect raindrops within a minute, it will go back to sleep. This is the crucial first step upon which the rest of this project will depend on.
    \item Calculate rainfall rate. If Tut-Tut can detect the frequency at which raindrops are falling, it has gained invaluable knowledge about its surrounding ecosystem.
    \item Calculate rainfall intensity. The microcontroller should be able to detect the intensity at which individual raindrops hit the device.
    \item Calculate individual raindrop size. The size of each raindrop (or average size) will be calculated from the data that Tut-Tut retrieves. 
    \item Integrate with the OPEnS mesh network of IoT devices around Oregon State University. We want these devices to communicate with one another and share data with a central server.
    \item Display this information to a user on a visually pleasing mobile application whose UI can be easily navigated so the user has minimal difficulty finding the data they are looking for.
\end{enumerate}

Upon completing these 6 steps, our Tut-Tut IoT Rainfall Detector will be completed

\bibliography{myref}
\bibliographystyle{ieeetr}

\end{document}

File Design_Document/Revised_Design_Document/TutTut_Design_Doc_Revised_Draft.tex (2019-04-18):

%\documentclass[10pt,a4paper]{article}
\documentclass[letterpaper,10pt,draftclsnofoot,onecolumn]{article}
\usepackage[letterpaper, margin=.75in]{geometry}

\usepackage{hyperref}
\usepackage{listings}
\usepackage{wasysym}
\usepackage{graphicx}

\hypersetup{
	colorlinks,
	citecolor=black,
	filecolor=black,
	linkcolor=black,
	urlcolor=black
}

\begin{document}
\begin{titlepage}
\vspace*{\fill}
\begin{center}
{\Large Tut-Tut, The IoT Rain Fall Detector Design Document}
\\[0.3cm]

{\large Team 21}
\\[0.3cm]

{\large CS 461 - Fall 2018}
\\[0.3cm]

{\large Michael Gillett, Casing and Microcontroller Lead}
\\[0.3cm]
{\large Jonathan Rohr, Data Collection and Management Lead}
\\[0.3cm]
{\large Shreyans Khunteta, UI Lead}
\\[0.3cm]

{\large November 26, 2018}
\\[1cm]

{\Large \textbf{Abstract}}
\end{center}
Tut-Tut, the IoT Raindrop Detector, is a project under the domain of the OPEnS (Openly Published Environment Sensing) Lab at Oregon State University. Tut-Tut will be able to detect a raindrop of any size, get an idea of the drop's mass from the intensity at which it falls, and detect the frequency of raindrops. After Tut-Tut gathers this data, it will be able to wirelessly transmit the information to a central server and communicate it to other IoT devices around Oregon State University. The detector will periodically wake up to check for rain and will stay awake as long as rain is detected within two minutes. If it does not detect raindrops within two minutes, it will go back to sleep. As a stretch goal, we will design an online mobile application to which the physical device will transmit information about the raindrops. If this stretch goal is not met, then the data will be stored in a Google Sheet.
\vspace*{\fill}
\end{titlepage}

\begin{center}
\section*{Glossary}
\end{center}

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

\pagebreak

\tableofcontents
\begin{center}
\begin{tabular}{ |p{0.3\linewidth}|p{0.3\linewidth}|p{0.3\linewidth}| }
\hline
\multicolumn{3}{|c|}{Revisions Table} \\
\hline
Section & Original & New \\
\hline
Overall &
Previously, this document consistently stated that Tut-Tut would be capable of measuring the specific mass of a raindrop. &
Now this document has changed all references to mass by replacing them with references to raindrop impact and intensity. Ultimately finding the specific mass of a raindrop was deemed out of scope for this project. \\
 && \\
2 &
The sensor will provide real-time information about the size/mass of the raindrops, how frequently they are falling and the intensity of the rainfall.. &
The sensor will provide real-time information about the relative size of raindrops when they impacts the sensor, how frequently they are falling, and the intensity of the rainfall. \\
 && \\
4.1 &
Using data gathered from the sensors, it will determine the size, density, mass, and frequency rate of these raindrops as they fall. &
Using data gathered from the sensors, it will determine the intensity of the rain based on the sensor impacts and the frequency rate of these raindrops as they fall.  \\
 && \\
4.1 &
These voltages can help determine the impact velocity and mass of the raindrops. &
Raindrops impacting the flat sensor will generate voltage that will be used to determine the intensity of the rain based on a specific range. \\
 && \\
\hline
\end{tabular}
\end{center}
\pagebreak

\section{Introduction}
\subsection{Purpose}
This document will outline the design specifications referenced in each of the group members' Tech Reviews. We will discuss the design of the pieces, technologies, methods, and other parts that will be included in the final product. The final product may differ slightly from the specifications in this document, but it should act as a roadmap moving forward.

\subsection{Scope}
When the Tut-Tut reaches the end of its development, it will be expected to perform three major tasks and one task that will be implemented if there is time. First, it will need to be able to translate vibrations from rainfall into a voltage using its onboard vibration sensors. Second, it will transmit the collected data to the OPEnS Lab's Dropbox where it is subsequently stored into a spreadsheet in real-time. Third, it must be integrated into their existing ecosystem of sensors, Loom. Finally, if time permits, a browser UI will be used to communicate the Tut-Tut data in an easy to understand way.

\subsection{Document Overview}
First, Michael details the code we will use in our Microcontroller and describes the protective casing that will encase all components of our project. Second, Jonathan describes how we will be collecting rainfall data with sensors and how that data will be sent to our online database. Finally, Shreyans outlines what our stretch goal website would look like. The group members will be primarily responsible for all the technologies in their respective sections for the remaining time frame of the entire project.

\section{System Overview}
This product is designed to accommodate any person(s) who may want to know about rainfall metrics in their area. The sensor will provide real-time information about the voltage when the raindrop falls on the sensor, how frequently they are falling, and the intensity of the rainfall. These metrics could be used by meteorologist as a way to show more detailed information about the rain in the local area. They could also be used by farmers to better take care of their crop fields. Furthermore, the Tut-Tut Rainfall Detector will link into the OPEnS lab's larger ecosystem of environmental devices and sensors, known as Loom. The data Tut-Tut collects will be stored in a Google Sheets database for analysis.

\section{System Architecture}

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

\subsection{Casing Design}
We have not yet done a model of Tut-Tut, but we do have a few expectations of what it should contain. First, we want the final product to be portable and able to be moved from place to place. To accomplish this we will need room in the casing for a battery, our microcontroller, and the sensor. Since the device will be out in rain, the casing containing the electronics will need to be weatherproof. The shape of Tut-Tut will likely be a 2 cm by 2 cm disk-shaped area on the top for raindrops to fall on, with a heavier base containing the hardware. Figure 1 shows what Tut-Tut might look like at the end of production given these specifications.
\newline

\begin{center}
Figure 1: A basic drawing of what Tut-Tut will resemble when complete

\end{center}

\subsection{Design Rationale}
Each of the pieces of Tut-Tut had to be chosen specifically regarding the purpose of the final product. Trade-offs were (or will be) made on both the sensor and microcontroller pieces. For the microcontroller, we had the option of a basic board, one with Wi-Fi capability, and one with Long-Range Radio capability. We chose the Wi-Fi model because of the constant connection and reliable transfers of data. The sensors available to us are a piezo, a MEMS, and an accelerometer. These devices are all similar in usage and will only change the specific design of the 3D-printed casing depending on which is chosen.

\section{Data Design}

\subsection{Data Collection}
Tut-Tut will use sensors to register vibrations from raindrops. Using data gathered from the sensors, it will determine the voltage upon impact and frequency rate of these raindrops as they fall. We will be using the Piezo Vibration Sensor and the Piezo Element to accomplish these tasks. 
\\
\\
The Piezo Vibration Sensor is a MEMS sensor which uses the piezoelectric effect to detect vibrations. It has dimensions of around 1 cm wide and 2 cm long. It has a high voltage sensitivity of 1 V/g at its baseline and 6 V/g at its resonance. The sensor generates AC and voltage when the thin film gyrates. These voltages can help determine the voltage upon impact of the raindrops, which allows us to see where they fall within a certain range.
\\
\\
The Piezo Element is a basic sensor that also uses the piezoelectric effect to detect vibrations. Raindrops impacting the flat sensor will generate voltage that will be used to determine where the raindrop falls within a certain range. The two sensors perform the same task in different ways, so they each will be tested to determine which one will work best for Tut-Tut.

\subsection{Data Management}
Tut-Tut will be gathering data in the field. This means no one will be around to monitor its results immediately. All of the data that is collected by the sensors above will have to be sent wirelessly, in real-time, to an internet hub. We will use the PushingBox to Google Sheet Pipeline that has already been discovered by the OPEnSLab.\cite{PushingBox} As our Arduino Board gathers data from the sensors, it will make GET requests to a PushingBox Scenario using the data to be sent as URL arguments. The PushingBox Scenario formats the data and sends it as URL arguments in its own GET request to the Google Sheet. The Google Sheet will then parse through and display the data. PushingBox currently only supports 1000 requests per day per user. This means that Tut-Tut will only be able to send a string of data once every two minutes.

\section{Human Interface Design}
Currently our scope for the UI is limited. All the information and relevant performance metrics will appear as an Excel spreadsheet you can access through a website link. However, our stretch goal is to create a fully functioning user interface that the user can navigate. This fully functional user interface will be on a website that looks fairly similar to the OPEnS lab website (http://www.open-sensing.org/). 
\newline

\begin{center}
Figure 2: The current OPEnS Lab website. Tut-Tut's website will resemble this in aesthetic.\cite{OPEnSLab}

\end{center}

\subsection{Overview of User Interface}
This user interface will be built with programming languages such as HTML, CSS and JavaScript. The user interface design is still in progress and it is important to stress that this is a stretch goal. However, we want the final appearance of it to be visually appealing and engaging, and to be be usable and understandable by any educated user, and not just the OPEnS lab staff and students.

\subsection{Screen Images}
The images on the screen will be pictures of OPEnS staff and OPEnS lab projects, such as Tut-Tut itself. It will remain tasteful and aesthetically pleasing, and will incorporate Oregon State logos as well. We will have it try to remain the OPEnS lab webpages themselves.

\subsection{Screen Objects and Actions}
We may implement some minor transitions between pages to make the site look more appealing to the user. However we are not going to use JavaScript effects for the sake of JavaScript effects. We want every transition we do to be for the ultimate comfort and ease of the user. Our design for this will flesh out as the project goes forward, as this is still our stretch goal.

\pagebreak

\section{Conclusion}
This document will generally outline the remainder of Tut-Tut's production and give us a road map in which to reference as needed. First, the code will constantly loop checking for forces read from the Piezo above our calculated threshold, and take appropriate action when an exerted force does cross it. Next, we will have all of our hardware components contained in a waterproof shell that is bottom-heavy with a 2x2 cm disk-shaped surface area to measure the rain drops as they hit. The resulting voltages will be translated into meaningful data and sent through the PushingBox to Google Sheet Pipeline. Finally, if time permits, we will create a UI based off the OPEnS Lab website. It will be easily navigable by any user and will have performance metrics that Tut-Tut will be tracking (raindrop size, intensity and frequency rate). If we are unable to meet this stretch goal, the UI will simply be a Google Sheets document with all the relevant performance metrics.

\pagebreak
\bibliography{reference}
\bibliographystyle{ieeetr}

\end{document}

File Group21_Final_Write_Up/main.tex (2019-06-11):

%\documentclass[10pt,a4paper]{article}
\documentclass[letterpaper,10pt,draftclsnofoot,onecolumn]{article}
\usepackage[letterpaper, margin=.75in]{geometry}

\usepackage{hyperref}
\usepackage{listings}
\usepackage{wasysym}
\usepackage{graphicx}

\graphicspath{ {./images/}}

\hypersetup{
	colorlinks,
	citecolor=black,
	filecolor=black,
	linkcolor=black,
	urlcolor=black
}
\begin{document}

\begin{titlepage}
\vspace*{\fill}
\begin{center}
{\Large Tut-Tut, The IoT Rain Fall Detector Final Hand Off Document}
\\[0.3cm]

{\large CS 461 - Spring 2019}
\\[0.3cm]

{\large Jonathan Rohr}
\\[0.3cm]

{\large Michael Gillett}
\\[0.3cm]

{\large Shreyans Khunteta}
\\[0.3cm]

{\large June 1st, 2019}
\\[1cm]

{\Large Abstract}
\end{center}
Tut-Tut, the IoT Raindrop Detector, is a project under the domain of the OPEnS (Openly Published Environment Sensing) Lab at Oregon State University. Tut-Tut will be able to detect a raindrop of any size, get an idea of the drop's mass from the intensity at which it falls, and detect the frequency of raindrops. After Tut-Tut gathers this data, it will be able to wirelessly transmit the information to a central server and communicate it to other IoT devices around Oregon State University. The detector will periodically wake up to check for rain and will stay awake as long as rain is detected within two minutes. If it does not detect raindrops within two minutes, it will go back to sleep. As a stretch goal, we will design an online mobile application to which the physical device will transmit information about the raindrops. If this stretch goal is not met, then the data will be stored in a Google Sheet.
\vspace*{\fill}
\end{titlepage}

\tableofcontents

\pagebreak

\section{Introduction}
In this document we will be outlining the requirements of Tut-Tut, the Internet of Things (IoT) Rainfall Detector. Requirements are as per requested by Chet Udell and the OPEnS Lab located at Oregon State University.

\subsection{Requested By Who and Why}
This project was requested by Chet Udell, on behalf of the OPEnS Lab at Oregon State University. The OPEnS Lab at Oregon State University is dedicated to developing technologies that increase our knowledge of the world we live in. They develop tools that can for example, detect the water content of soil across a patch of farm land, and give real time updates about their conditions. If the field is getting too much water in one particular area, their technology could tell the the sprinkler system in that area to start watering  the sections of the field in desperate need of water based on the water content readings.

\subsection{Team members and roles}
The members of this team were Jonathan Rohr, Michael Gillett and Shreyans Khunteta.  Jonathan focused primarily on the microcontroller and coding. Michael focused primarily on 3D printing and designing the physical casing. Shreyans also focused on 3D printing as well as being the primary writer of documentation. However, all members of the team participated somewhat in most aspects of the project and all members communicated their tasks and how to do them with one another. This was so that if one person was unable to complete that task, someone else would be able to pick it up. 

%\tableofcontents
\begin{center}
\begin{tabular}{ |p{0.3\linewidth}|p{0.3\linewidth}|p{0.3\linewidth}| }
\hline
\multicolumn{3}{|c|}{Requirements Doc Revisions Table} \\
\hline
Section & Original & New \\
\hline
Overall &
Previously, this document consistently stated that Tut-Tut would be capable of measuring the specific mass of a raindrop. &
Now this document has changed all references to mass by replacing them with references to raindrop impact and intensity. Ultimately finding the specific mass of a raindrop was deemed out of scope for this project. \\
 & \\
2.2 &
The main functions of this raindrop detector are that it can detect raindrop size, frequency rate and intensity. &
The main functions of this raindrop detector are that it can detect raindrop impacts, frequency rate and relative intensity of the rainfall based on the raindrop impacts. \\
 & \\
2.2 &
It will also upload its data to a central server where the information can be viewed in a Google Sheet. &
It will also upload its data to a central server where the information can be viewed in a Google Sheet. It will need to go to sleep while it is not raining so that the battery does not drain. \\
 & \\
3.2 &
It will be able to detect the size of a raindrop, the frequency at which rain is falling, and the intensity at which it hits the detector. &
It will be able to detect the raindrop impacts, the frequency at which rain is falling, and the intensity at which it hits the detector. The device will also need to go to sleep while it is not raining to conserve battery. It will awaken when it can detect rain falling and will continue gathering data. \\
 & \\
\hline
\end{tabular}
\end{center}

\section{Requirements Doc Introduction}
In this document we will be outlining the requirements of Tut-Tut, the Internet of Things (IoT) Rainfall Detector. Requirements are as per requested by Chet Udell and the OPEnS Lab located at Oregon State University.

\subsection{Purpose}
This document intends to guide development of Tut-Tut over the course of 7 months. It will go through changes in the duration of the project as new information makes itself clear.

\begin{enumerate}
    \item \textbf{Draft:}  The first draft is written by the development team after requirements have been outlined by their client. 
    \item \textbf{Proposal:} The drafted document will be passed along to all other parties involved, including the client, OPEnS lab team, and course professors, who will evaluate the requirements outlines and request changes where necessary.
    \item \textbf{Approved:} The document is considered approved when it is accepted by all parties. Following this, the development team can begin implementing their technology using the document as a guide.
\end{enumerate}

\subsection{Target Audience}
This product is designed to accommodate any person(s) who may want to know about rainfall metrics in their area. The sensor will provide real-time information about the relative intensity of the rain based on the impacts of the drops and how frequently they are falling. These metrics could be used by meteorologist as a way to show more detailed information about the rain in the local area. Furthermore, the Tut-Tut Rainfall Detector will link into the OPEnS lab's larger ecosystem of environmental devices and sensors, known as Loom.

\subsection{Project Scope}
%describes the expectations of the product if it were to hit the market, e.g. what must be done to deliver the working product
When the Tut-Tut is finished at the end of the development period, it will be expected to perform three major tasks and one task that will be implemented if there is time. First, it will need to be able to translate vibrations from rainfall using its on-board vibration sensors. Second, it will transmit the collected data to an internet hub where it is subsequently uploaded to Google Sheets in real-time. Third, it must be integrated into the existing OPEnS Lab's ecosystem of sensors and devices called Loom. Finally, if time permits, a browser UI will be used to communicate the Tut-Tut data in an easy to understand way.

\subsection{Business Case for the Product}
%Why do we need this product in the world?
From a business standpoint, this product could deliver an understanding of the rainfall for different areas in the form of a comprehensive map. If the Tut-Tut rainfall detector were to be placed around the country, it could tell you about the type of rain that falls in a given region. Rain on the East Coast might be more of a mist, while the rain in Oregon falls quickly and intense. Tut-Tut would give us the data to show those claims in the form of data it gathers.

\subsection{Overview}
%Summary of the requirements, a general idea
In order to create this device, we will need to program our microcontroller, test vibration sensors, design and 3D print the enclosure, store all code in a github repository, integrate it into Loom, and if possible, create a browser UI as a way to highlight useful information in the spreadsheets.

\section{Requirements Doc General Description}
%SECTION TWO, THE REAL DEAL
%Non-technical description, easily read in laymans terms
The IoT raindrop detector will be used to record the amount of rainfall in a particular area. This can be particularly useful in agricultural farming, as this means farmers will know exactly how much rainfall their crops are getting and this way the farmers know how much rainfall they have to provide their crops. 

\subsection{Product Perspective}
%Why are we developing this product?
The thought behind this product's development is that the Loom network managed by Oregon State's OPEnS lab lacks a device that provides more specific details about rainfall. When this product is finished and integrated into their network, the findings might be significant enough to allow Tut-Tut to be available to the public. Even if the data turns out to only be significant to a small population of people, we still will have helped out those individuals, and the Loom network will have a new integration that could inspire similar devices.

\subsection{Product Functions}
%What does it do? Main functions
The main functions of this raindrop detector are that it can detect raindrop impacts, frequency rate and relative intensity of the rainfall based on the raindrop impacts. It also will link up with the network of IoT devices maintained by the OPEnS lab. It will also upload its data to a central server where the information can be viewed in a Google Sheet. It will need to go to sleep while it is not raining so that the battery does not drain.

\subsection{End User Characteristics}
%What would someone using the final product expect from it? Who would that person be? Do they need a technical background or can they use it right away with no prior knowledge of its development?
If we develop the mobile application (which is our stretch goal), the end user can be anyone capable of using the interface. We plan to have a user-friendly interface where anyone can use the application to see the performance metrics of the IoT device.
\newline
If we don't meet the stretch goal, the end user will be anyone able to use the Loom network of IoT devices around Oregon State. This project will be then used next year for another Capstone team to build off of.

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

\subsection{Assumptions and Dependencies}
%Dependencies (internet connection within range, battery or plug, etc) Assumptions (End User skills or prior knowledge)
Using this product effectively will require an internet connection and a power source. The Feather M0 microcontroller comes equipped with a Wi-Fi card, so anywhere on the university should be suitable enough for Tut-Tut. Using the device anywhere else must have a Wi-Fi signal within range. Another dependency is the power source. Because Tut-Tut is intended to be moved around, Tut-Tut should run on a battery. The type of battery we will use is undetermined, and will be figured out in the testing phase. Users should need no prior knowledge to configure and set up Tut-Tut.

\section{Requirements Doc Specific Requirements}
This section of the document lists specific requirements for Tut-Tut. Requirements will be divided into three sections:
\begin{enumerate}
    \item \textbf{User Requirements: } These are requirements written from the point of view of the end users who will be using the product.
    \item \textbf{System Requirements: } These are the detailed specifications that the product's internal hardware will need to be capable of doing.
    \item \textbf{Interface Requirements: } These are the requirements about how the information gathered by the device will be presented 
\end{enumerate}

\subsection{User Requirements}
%Minimal, since the information will be understood by everyone
The user will, provided our stretch goal is met, be anyone. The information will be easily accessible and understandable. Even if our stretch goal isn't met, we will still display our data gathered in a Google Sheet that should be able to be understood by anyone.

\subsection{System Requirements}
%2x2 inch sensor capable of detecting even the most minute amounts of rain, Wi-Fi or network capabilities, able to be integrated with mesh network, waterproof
The system will be a 2x2 inch weather resistant sensing area capable of detecting even the most minute amounts of rain. It will have Wi-Fi or network capabilities and we will be able to integrate it easily with the IoT mesh network around the university. It will be able to detect the raindrop impacts, the frequency at which rain is falling, and the intensity at which it hits the detector. The device will also need to go to sleep while it is not raining to conserve battery. It will awaken when it can detect rain falling and will continue gathering data.

\subsection{Interface Requirements}
%needs to be accessible and give accurate or clear information. Perhaps in the form of a generated map visual, or a twitter bot.
The interface for the mobile application, if the stretch goal isn't met, will just be an Excel spreadsheet with all the data cleanly labelled. If the stretch goal is met, it will be a mobile application that can easily be navigated. The specifics of the application's appearance will be worked out, but it will be easy to look at and trivial for an inexperienced user to find all the information they are looking for.

\section{Requirements Doc Gantt Chart}
%Chart outlining the timeline of this project. Term one is design, Term two is bulding, and Term 3 is testing. That's my only information



\begin{titlepage}
\vspace*{\fill}
\begin{center}

{\Large Tut-Tut, The IoT Rain Fall Detector Design Document}
\\[0.3cm]

{\large Team 21}
\\[0.3cm]

{\large CS 461 - Fall 2018}
\\[0.3cm]

{\large Michael Gillett, Casing and Microcontroller Lead}
\\[0.3cm]
{\large Jonathan Rohr, Data Collection and Management Lead}
\\[0.3cm]
{\large Shreyans Khunteta, UI Lead}
\\[0.3cm]

{\large November 26, 2018}
\\[1cm]

{\Large \textbf{Abstract}}
\end{center}
Tut-Tut, the IoT Raindrop Detector, is a project under the domain of the OPEnS (Openly Published Environment Sensing) Lab at Oregon State University. Tut-Tut will be able to detect a raindrop of any size, get an idea of the drop's mass from the intensity at which it falls, and detect the frequency of raindrops. After Tut-Tut gathers this data, it will be able to wirelessly transmit the information to a central server and communicate it to other IoT devices around Oregon State University. The detector will periodically wake up to check for rain and will stay awake as long as rain is detected within two minutes. If it does not detect raindrops within two minutes, it will go back to sleep. As a stretch goal, we will design an online mobile application to which the physical device will transmit information about the raindrops. If this stretch goal is not met, then the data will be stored in a Google Sheet.
\vspace*{\fill}

\end{titlepage}

\begin{center}
\section*{Glossary}
\end{center}

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

\pagebreak

%\tableofcontents
\begin{center}
\begin{tabular}{ |p{0.3\linewidth}|p{0.3\linewidth}|p{0.3\linewidth}| }
\hline
\multicolumn{3}{|c|}{Design Document Revisions Table} \\
\hline
Section & Original & New \\
\hline
Overall &
Previously, this document consistently stated that Tut-Tut would be capable of measuring the specific mass of a raindrop. &
Now this document has changed all references to mass by replacing them with references to raindrop impact and intensity. Ultimately finding the specific mass of a raindrop was deemed out of scope for this project. \\
 & \\
2 &
The sensor will provide real-time information about the size/mass of the raindrops, how frequently they are falling and the intensity of the rainfall.. &
The sensor will provide real-time information about the relative size of raindrops when they impacts the sensor, how frequently they are falling, and the intensity of the rainfall. \\
 & \\
4.1 &
Using data gathered from the sensors, it will determine the size, density, mass, and frequency rate of these raindrops as they fall. &
Using data gathered from the sensors, it will determine the intensity of the rain based on the sensor impacts and the frequency rate of these raindrops as they fall.  \\
 & \\
4.1 &
These voltages can help determine the impact velocity and mass of the raindrops. &
Raindrops impacting the flat sensor will generate voltage that will be used to determine the intensity of the rain based on a specific range. \\
 & \\
\hline
\end{tabular}
\end{center}

\section{Design Document Introduction}
\subsection{Purpose}
This document will outline the design specifications referenced in each of the group members' Tech Reviews. We will discuss the design of the pieces, technologies, methods, and other parts that will be included in the final product. The final product may differ slightly from the specifications in this document, but it should act as a roadmap moving forward.

\subsection{Scope}
When the Tut-Tut reaches the end of its development, it will be expected to perform three major tasks and one task that will be implemented if there is time. First, it will need to be able to translate vibrations from rainfall into a voltage using its onboard vibration sensors. Second, it will transmit the collected data to the OPEnS Lab's Dropbox where it is subsequently stored into a spreadsheet in real-time. Third, it must be integrated into their existing ecosystem of sensors, Loom. Finally, if time permits, a browser UI will be used to communicate the Tut-Tut data in an easy to understand way.

\subsection{Document Overview}
First, Michael details the code we will use in our Microcontroller and describes the protective casing that will encase all components of our project. Second, Jonathan describes how we will be collecting rainfall data with sensors and how that data will be sent to our online database. Finally, Shreyans outlines what our stretch goal website would look like. The group members will be primarily responsible for all the technologies in their respective sections for the remaining time frame of the entire project.

\section{Design Document System Overview}
This product is designed to accommodate any person(s) who may want to know about rainfall metrics in their area. The sensor will provide real-time information about the voltage when the raindrop falls on the sensor, how frequently they are falling, and the intensity of the rainfall. These metrics could be used by meteorologist as a way to show more detailed information about the rain in the local area. They could also be used by farmers to better take care of their crop fields. Furthermore, the Tut-Tut Rainfall Detector will link into the OPEnS lab's larger ecosystem of environmental devices and sensors, known as Loom. The data Tut-Tut collects will be stored in a Google Sheets database for analysis.

\section{Design Document System Architecture}

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

\subsection{Casing Design}
We have not yet done a model of Tut-Tut, but we do have a few expectations of what it should contain. First, we want the final product to be portable and able to be moved from place to place. To accomplish this we will need room in the casing for a battery, our microcontroller, and the sensor. Since the device will be out in rain, the casing containing the electronics will need to be weatherproof. The shape of Tut-Tut will likely be a 2 cm by 2 cm disk-shaped area on the top for raindrops to fall on, with a heavier base containing the hardware. Figure 1 shows what Tut-Tut might look like at the end of production given these specifications.
\newline

\begin{center}
Figure 1: A basic drawing of what Tut-Tut will resemble when complete

\end{center}

\subsection{Design Rationale}
Each of the pieces of Tut-Tut had to be chosen specifically regarding the purpose of the final product. Trade-offs were (or will be) made on both the sensor and microcontroller pieces. For the microcontroller, we had the option of a basic board, one with Wi-Fi capability, and one with Long-Range Radio capability. We chose the Wi-Fi model because of the constant connection and reliable transfers of data. The sensors available to us are a piezo, a MEMS, and an accelerometer. These devices are all similar in usage and will only change the specific design of the 3D-printed casing depending on which is chosen.

\section{Design Document Data Design}

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

\subsection{Data Management}
Tut-Tut will be gathering data in the field. This means no one will be around to monitor its results immediately. All of the data that is collected by the sensors above will have to be sent wirelessly, in real-time, to an internet hub. We will use the PushingBox to Google Sheet Pipeline that has already been discovered by the OPEnSLab.\cite{pushingbox} As our Arduino Board gathers data from the sensors, it will make GET requests to a PushingBox Scenario using the data to be sent as URL arguments. The PushingBox Scenario formats the data and sends it as URL arguments in its own GET request to the Google Sheet. The Google Sheet will then parse through and display the data. PushingBox currently only supports 1000 requests per day per user. This means that Tut-Tut will only be able to send a string of data once every two minutes.

\section{Design Document Human Interface Design}
Currently our scope for the UI is limited. All the information and relevant performance metrics will appear as an Excel spreadsheet you can access through a website link. However, our stretch goal is to create a fully functioning user interface that the user can navigate. This fully functional user interface will be on a website that looks fairly similar to the OPEnS lab website (http://www.open-sensing.org/). 
\newline

\begin{center}
Figure 2: The current OPEnS Lab website. Tut-Tut's website will resemble this in aesthetic.\cite{OPEnSLab}

\end{center}

\subsection{Overview of User Interface}
This user interface will be built with programming languages such as HTML, CSS and JavaScript. The user interface design is still in progress and it is important to stress that this is a stretch goal. However, we want the final appearance of it to be visually appealing and engaging, and to be be usable and understandable by any educated user, and not just the OPEnS lab staff and students.

\subsection{Screen Images}
The images on the screen will be pictures of OPEnS staff and OPEnS lab projects, such as Tut-Tut itself. It will remain tasteful and aesthetically pleasing, and will incorporate Oregon State logos as well. We will have it try to remain the OPEnS lab webpages themselves.

\subsection{Screen Objects and Actions}
We may implement some minor transitions between pages to make the site look more appealing to the user. However we are not going to use JavaScript effects for the sake of JavaScript effects. We want every transition we do to be for the ultimate comfort and ease of the user. Our design for this will flesh out as the project goes forward, as this is still our stretch goal.

\pagebreak

\section{Design Document Conclusion}
This document will generally outline the remainder of Tut-Tut's production and give us a road map in which to reference as needed. First, the code will constantly loop checking for forces read from the Piezo above our calculated threshold, and take appropriate action when an exerted force does cross it. Next, we will have all of our hardware components contained in a waterproof casing that is bottom-heavy with a 2x2 cm disk-shaped surface area to measure the rain drops as they hit. The resulting voltages will be translated into meaningful data and sent through the PushingBox to Google Sheet Pipeline. Finally, if time permits, we will create a UI based off the OPEnS Lab website. It will be easily navigable by any user and will have performance metrics that Tut-Tut will be tracking (raindrop size, intensity and frequency rate). If we are unable to meet this stretch goal, the UI will simply be a Google Sheets document with all the relevant performance metrics.

\begin{titlepage}
\vspace*{\fill}
\begin{center}
{\Large Tut-Tut, The IoT Rain Fall Detector Tech Review}
\\[0.3cm]

{\large Team 21}
\\[0.3cm]

{\large CS 461 - Fall 2018}
\\[0.3cm]

{\large Jonathan Rohr, Data Collection and Management Lead}
\\[0.3cm]

{\large November 1, 2018}
\\[1cm]

{\Large Abstract}
\end{center}
Tut-Tut, the IoT Raindrop Detector, is a project under the domain of the OPEnS (Openly Published Environment Sensing) Lab at Oregon State University. Tut-Tut will be able to detect a drop of any size, get an idea of the raindrop mass from the intensity at which it falls, and detect the frequency of raindrops. After Tut-Tut gathers this data, it will be able to wirelessly transmit the information to a central server and store it in a database. This document will explore multiple possible technologies that can be used to gather, transmit, and store our data.
\vspace*{\fill}
\end{titlepage}

\section{Jonathan Tech Review Introduction}
Tut-Tut will be fully designed and 3D printed at the OPEnS lab. It will have a flat, circular sensor that can detect and measure minuscule hits and turn the Mechanical Energy produced into voltage for our microcontroller. The kinds of sensors that can achieve this are a piezo, a MEMS, or an accelerometer. These all have nearly the same functionality, but we will conduct tests on all 3 of them to see which fits our needs best. The flat sensor will be hooked up to a Feather m0 microcontroller that we will program using Artuino IDE. The microcontroller will be how we incorporate the readings and data manipulation we want, and also how we relay that information to the remote server. The data will be sent to the server using PushingBox API and will be stored in Google Sheets as it waits to be be parsed and analyzed. This document will review each type of sensor and explore alternate means of transmitting and storing the data.

\subsection{Collecting Data with a Sensor}
Tut-Tut will use a sensor to register the vibrations from raindrops. It will use the data from the sensor to determine the density, size, and speed of the rain drops. There are a variety of sensors that are capable of performing this task. Below are details on three types of sensors we will be physically testing before beginning our project so we can select the one most appropriate for our needs. The specific sensors that we end up using may be different from the ones referenced.

\begin{enumerate}
    \item \textbf{Grove - Piezo Vibration Sensor:} A piezoelectric sensor is any device that measures variables such as pressure, acceleration, and force using the piezoelectric effect. The sensor converts the forces it is subjected to into electrical charges which can be recorded and analyzed. \cite{piezosensor} For example, the Grove-Piezo Vibration Sensor offered by Seeedstudio can use the piezoelectric effect to measure vibration, impact, and touch. The sensor's sensitivity can be easily adjusted so we can gather precise data. It is lightweight, small, and thin which will help portability and aid in keeping Tut-Tut as small as possible. Their sensors have been used in car alarms, security systems, and low power wakeup switches. \cite{grovepiezosensor}
    \item \textbf{Accelerometer:} An accelerometer is a device that measures vibrations from acceleration forces using electromechanical technology. They measure the forces as voltage and then translate those voltages into a vibration measurement. \cite{accelerator} These measurements allow us to determine how fast the raindrops are as they impact the sensor, how much force is exerted on the sensor with each impact, and the frequency of the impacts. With this data we could figure out the density of the rain among other important factors. There are various types of accelerometers, including those that utilize the piezoelectric effect like the one above. Their are some that are meant to be as small as possible like the MEMS sensors described below.
    \item \textbf{Microelectromechanical Systems (MEMS) Accelerometer:} MEMS has to do with microscopic devices and systems. A MEMS accelerometer is an extremely tiny device that can perform all of the same sensing capabilities as an ordinary accelerometer. The accelerometers that utilize MEMS technology are usually the Capacitive type. They differ from their piezoelectric brothers by measuring the change of capacitance in the mass due to acceleration. MEMS allows these accelerometers to be cheaper and more compact. Unfortunately, most capacitive accelerometers suffer from a problem with high frequency noise due in part to their internal clocks and size. \cite{mems} This may not be an issue for our project, but it is important to keep in mind when analyzing our test data. 
\end{enumerate}

\subsection{Sending Data to an Internet Hub}
Tut-Tut will be gathering data in the field. This means no one will be around to monitor its results immediately. All of the data that is collected by the sensors above will have to be sent wirelessly, in real-time, to an internet hub. The best way to do this is by using the PushingBox API in the Arduino IDE. However, if that option didn't exist, there are two other possible ways of retrieving the data.

\begin{enumerate}
    \item \textbf{PushingBox API:} As stated above, the PushingBox API is the best way to send data to the internet hub in real-time. The main purpose of PushingBox is to instantly send notifications in various ways (emails, tweets, smartphone push notifications, HTTP requests, etc.) and can be called using Arduino. \cite{pushingbox} What we strive to do, however, is to push chunks of data in real-time to Google Sheets for storage. Luckily, the open-sensing team at Oregon State University has found a way to utilize PushingBox's real-time delivery of HTTP Ethernet data. We can use PushingBox API to transmit the HTTP data in a way that Google can recognize it as compliant HTTPS encrypted data. \cite{realtimepushingbox} With this system, we can continuously transmit data that Tut-Tut collects and store it directly into Google Sheets. Other data logging techniques require expensive secondary systems or creative solutions. This makes the PushingBox method the easiest and most effective way at transmitting our data from the device to the internet hub and directly into Google Sheets.
    \item \textbf{Omni Instruments Data Loggers:} If PushingBox wasn't available to us, then we may be forced to use other means of transmitting the data from Tut-Tut. One way is to hook it up to a GRD-3G Series Data Logger with Mobile and Satellite Communications which is offered by Omni Instruments. These devices are meant to be used to connect sensors to a communications network and transmit the found data to designated databases and/or web interfaces. The Data Logger is durable, reliable, and configurable. However, it suffers from bulkiness and excessive price. Depending on the features included, one device can cost between \$800 and \$1000. These devices are intended to be used for larger projects that transmit larger amounts of data than Tut-Tut and require a larger, near-global range. \cite{omni} 
    \item \textbf{SIM900A GSM Module:} If Tut-Tut was not able to connect to the internet hub because either it lacked the wireless adapter or it malfunctioned, a SIM900A GSM module could be used as a creative solution. Given the SIM900A has a working SIM card and is able to connect to the internet, it can be used to transmit data to a website or online database. Jens Christoffersen used a SIM900A GSM module to send temperature and humidity data to his website while he is was at the marina or at sea in his boat. He figured out a way to use a microcontroller, a SIM900A GSM module, various additional parts, and some PHP to transmit data from his sensors. \cite{jens} If this technology was to be applied to Tut-Tut, it would no longer need to have a constant connection to Wi-Fi. It could be placed in the middle of a forest and as long as it could connect to the cell towers, it would be able to still transmit data.
\end{enumerate}

\subsection{Storing and Managing Data}
All the sensor data that Tut-Tut will collect needs to be stored and managed somewhere. Preferably, it would be an online database of some kind so that multiple team members can view and analyze the data. It should also be organized and the GUI should be user friendly.
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

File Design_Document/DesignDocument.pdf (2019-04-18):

## Tut-Tut, The IoT Rain Fall Detector Design Document

Team 21

CS 461 - Fall 2018

Michael Gillett, Casing and Microcontroller Lead

Jonathan Rohr, Data Collection and Management Lead

Shreyans Khunteta, UI Lead

November 26, 2018

## Abstract

Tut-Tut, the IoT Raindrop Detector, is a project under the domain of the OPEnS (Openly Published Environment Sensing) Lab at Oregon State University. Tut-Tut will be able to detect a drop of any size, get an idea of the raindrop mass from the intensity at which it falls, and detect the frequency of raindrops. After Tut-Tut gathers this data, it will be able to wirelessly transmit the information to a central server and communicate it to other IoT devices around Oregon State University. The detector will have a 2 cm by 2 cm area it can sense rain in, will wake up with a single raindrop, and will stay awake as long as more rain is detected within a minute. In addition to the physical device, we will also design a browser UI to make the gathered data more readable.
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

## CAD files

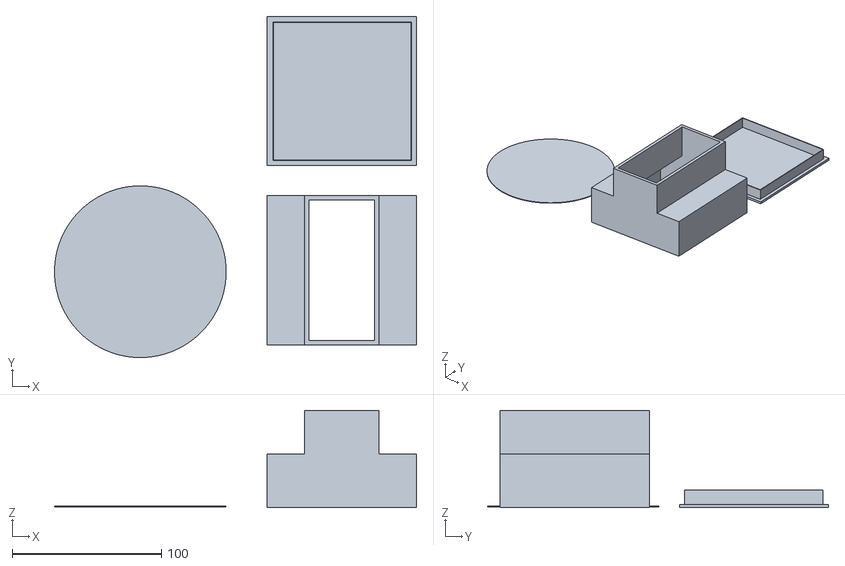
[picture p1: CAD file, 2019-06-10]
Fusion360_Files/Final-Prototype-TutTut.stl
242.5 x 228.5 x 65.0

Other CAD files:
Fusion360_Files/Final-Printed-Prototype v1.f3d

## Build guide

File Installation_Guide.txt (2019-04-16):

Tut-Tut Installation Guide

Step 1: Navigate to https://www.arduino.cc/en/Main/Software and select the appropriate download based on your operating system.

Step 2: Install the latest Arduino IDE version.

Remaining steps based on Windows version

Step 3: By default, the installation will place an Arduino folder in the Documents System Folder. Other destinations can be specified during the installation.

Step 4: Move the libraries and piezo_vibration_sensor folders from the TutTut_Code folder of this repository into the Arduino folder at your specified destination.

Step 5: Move into the piezo_vibration_sensor folder and open the piezo_vibration_sensor.ino file. This will launch the Arduino IDE.

Step 6: Additionally, open up the config.h file and navigate to the WIFI SETTINGS section. Change the DEFAULT_NETWORK and DEFAULT_PASSWORD to the desired network and password.

Step 7: Connect the TutTut device to your computer via a microUSB cable.

Step 8: In the Arduino IDE, click the Tools dropdown menu at the top.

Step 9: Where it says Board: "XXXXX", select Adafruit Feather M0 from the additional dropdown menu.

Step 10: Now press the upload button (Right Arrow) to compile and upload the sketch to the microcontroller in the Tut-Tut Device.

Step 11: The code should start immediately after the upload is complete and will continue to run unless disconnected from power. The USB can now be disconnected and the battery can be connected.

Tut-Tut Installation Guide Command Line On Linux

Step 1: Go to Arduino site and follow the necessary steps listed: https://www.arduino.cc/en/guide/linux

Step 2: Once installed, follow similar steps to the above to upload the sketch to the microcontroller.

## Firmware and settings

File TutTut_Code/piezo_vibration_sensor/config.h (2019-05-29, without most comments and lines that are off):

#define FAMILY 		"LOOM"		// Will usually be "LOOM", you can change this if you are setting up your own network
#define FAMILY_NUM       1		// Specifies the subnet of the family that the device is on. 0 for elevated permissions (can communicate with any subnet), 1-9 for normal
#define CHANNEL          1		// Channel to use. Set to 1-8 for channels A-H, respectively (on WiFi), LoRa can use 1-9. Alternatively can define to -1 to used advanced option INIT_INST
#define REQUEST_SETTINGS 0		// 1 to request dynamic channel settings (i.e. next available channel) from MaxMSP Channel Manager, 0 to not
#define AUTO_NAME        0		// 1 to enable naming device based on configured settings (if not set manual name in advanced options)
#define CUSTOM_NAME "TutTut"	// This is only used if Auto_name is set to be 0
#define LOOM_DEBUG    0
#define dynamic_serial_output 0 // These only apply if LOOM_DEBUG is enabled
#define wake_delay 0			// 1 to enable wait 5 seconds upon awaking from sleep to (re)start Serial before program continue (useful for reprogramming if device quickly goes back to sleep)
#define prevent_platform_compile_error 0  	// 0: Allow errors to be triggered if the program calls
#define display_config 1		// 1 to print the uploaded configuration at start of setup, 0 to not
#define hub_node_type 1		// 0: Hub, 1: Node
#define is_repeater   0		// Sorry, this doesn't do anything yet
#define is_ishield      0	// 1 to specify using Ishield (generally used on WiFi)
#define is_multiplexer  0	// 1 to specify Multiplexer (tca9548a) is being used
#define is_sapflow      0	// 1 to specify Sapflow
#define is_evaporimeter 0	// 1 to specify Evaporimeter
#define is_wifi       1		// 1 to enable WiFi
#define is_lora       0		// 1 to enable LoRa (cannot be used with nRF) (Further customization in advanced options)
#define is_nrf        0		// 1 to enable nRF (cannot be used with LoRa) (Further customization in advanced options)
#define is_ethernet   0		// 1 to enable Ethernet (a number of options below might auto enable this anyway though)
#define is_fona       0		// 1 to enable cellular via Fona (808 version)
#define is_pushingbox 1		// 1 to enable PushingBox
#define is_rtc        0		// Enable RTC functionality
#if is_rtc == 1
	#define RTC_pin 		6	// What pin the RTC interrupt is connected to
	#define use_utc_time 	1 	// 1 to use UTC time rather than local
	enum TimeZone {
		WAT, AT, ADT, AST, EDT, EST, CDT, CST, MDT, MST, PDT, PST, ALDT,
		ALST, HST, SST, GMT, BST, CET, CEST, EET, EEST, BT, ZP4, ZP5,
		ZP6, ZP7, AWST, AWDT, ACST, ACDT, AEST, AEDT
	};
	TimeZone timezone = PST;
	#define is_rtc3231 0 	// RTC DS 3231 Featherwing
	#define is_rtc8523 0	// RTC Adalogger Featherwing with PCF8523 RTC (the one with SD card)
	#define get_time_from_internet 0
#endif
#define is_sd         0		// 1 to enable SD card
#if is_sd == 1
	#define sdSaveFilter  	 1 	// 1 to enable a millis delay to SD
	#define sdSaveMinDelay   1  // minimum delay in seconds between saves (only applies sdSaveFilter is 1)
	#define sdBroadcastSave  0  // 1 to broadcast on communication platforms when data is saved to SD, 0 to not
#endif
#define is_oled 					0 	// Whether OLED is being used
#if is_oled == 1
	#define oled_form_factor 	1		// 1 for Featherwing Shield, 2 for breakout
	#if oled_form_factor == 2
		#define oled_reset_pin A2  			// Make sure this doesn't conflict with other pins in use
	#endif
	#define oled_display_format 3     	// 1: show first 4 elements of the bundle
	#if oled_display_format == 3
		#define oled_scroll_duration 8	// The time (in seconds) to scroll through a bundle
		#define oled_button_freeze	 2	// 0: Disable button freezing
		#define oled_freeze_pin		 10	// Which pin to read from to freeze display
	#endif
#endif
#define num_servos    0 	// Number of servos being used (up to 8 per shield, testing has generally only been through 1 shield)
#define num_steppers  0		// Number of stepper motors being used
#define is_relay      0		// 1 if a relay is being used
#if is_relay == 1
	#define relay_pin 10	// Digital pin connected to the relay enable
#endif
#define is_button 		0	// 1 to enable button
#define button_pin 		10	// Pin button is attached to
#define is_analog     0		// 1 if analog input is being used, 0 if not
	#define is_analog_a0 1
	#define is_analog_a1 1
	#define is_analog_a2 0
	#define is_analog_a3 0
	#define is_analog_a4 0
	#define is_analog_a5 0
#define analog_samples 16 	// Must be 1, 2, 4, 8, or 16 number of analog measurements to sample and average
#define is_decagon    0		// 1 if GS3 Decagon is being used
#define is_as726X          0	// Spectral Sensor (visible 7262 /near IR 7263) [cannot be used with TSL2561 or AS7265X]
#define is_as7265X         0	// Spectral Sensor Triad [cannot be used with TSL2561 or AS726X]
#define is_tsl2591         0	// Lux Sensor
#define is_tsl2561         0	// Lux Sensor [cannot be used with AS726X or AS7265X]
	#if is_tsl2561 == 1
		#define tsl2561_res 3 // 1 for fastest, low-res, 2 for middle, 3 for slow, high-res
	#endif
#define is_fxos8700        0	// Accelerometer / Magnetometer
#define is_fxas21002       0	// Gyroscope
#define is_zxgesturesensor 0	// ZX Distance Sensor
#define is_sht31d          0	// Temperature / Humidity
#define is_mb1232          0	// Sonar
#define is_mpu6050         0	// Accelerometer / Gyroscope
#define is_lis3dh          0	// Accelerometer
#define is_ms5803          0	// Atmospheric Pressure / Temperature Sensor
#define is_hx711           0    // Load Cell
	#if is_hx711 == 1
		#define hx711_calibration 961.275
	#endif
#if is_wifi == 1
	#define DEFAULT_MODE      WPA_CLIENT_MODE	// AP_MODE, WPA_CLIENT_MODE or WEP_CLIENT_MODE
  #define DEFAULT_NETWORK   "TutTut"     // Network SSID / name
  #define DEFAULT_PASSWORD  "12345432"    // Network password
#endif
#define enable_flash 1   			// 1 is the default, 0 to turn of reading and writing to flash/EEPROM memory
#define enable_hub_scripts 0		// RPN script parser
#define advanced_interdev_comm   0	// 1 to use Max-like functionality
#define build_actuator_cmd_funcs 0  // 1 to include file to make commands for Loom actuators
#define skip_mpu_cal 1
#if CHANNEL == -1
	#define INIT_INST   	 3	// Initial device instance number (normally 1-9 when using channels)
	#if is_wifi == 1
		#define INIT_PORT 9443	// Initial device UDP port (normally 1-9 when using channels)
	#endif
#endif
#if is_wifi == 1
	#define advanced_interdev_comm 1 	// Enable for full Max support
#endif
#if LOOM_DEBUG == 1
	#define SERIAL_BAUD 115200 			// Select Serial baudrate, only used supported rates (i.e. 9600, or 115200, etc.)
#endif
#if is_ishield == 1
	#define is_button     1			// 1 to enable button
	#define button_pin    10		// Pin that the button uses
	#define is_mpu6050    1 		// Enables MPU6050 on Ishield
	#define is_neopixel   1			// Toggle based on whether Neopixels are being used
	#define is_analog     1
	#define is_analog_a0 1			// 1 to enable Feather A_ ports as analog inputs
	#define is_analog_a1 1
	#define is_analog_a2 0
	#define is_analog_a3 0
	#define is_analog_a4 0
	#define is_analog_a5 0
	#if is_neopixel == 1			// Which Ishield ports to enable Neopixels for
		#define NEO_0     0			// Port 0 (A0, closest to end of Ishield)
		#define NEO_1     0			// Port 1 (A1, middle port)
		#define NEO_2     1			// Port 2 (A2, port closest to MPU6050)
	#endif
#endif
#if is_multiplexer == 1
	#define UPDATE_PERIOD 5000		// Milliseconds between multiplexer sensor list being updated
	#define is_as726X          0 	// Spectral Sensor (visible 7262 /near IR 7263) [cannot be used with TSL2561 or AS7265X]
	#define is_as7265X         1	// Spectral Sensor Triad [cannot be used with TSL2561 or AS726X]
	#define is_fxas21002       1	// Gyroscope
	#define is_fxos8700        1	// Accelerometer / Magnetometer
	#define is_lis3dh          1    // Accelerometer
	#define is_mb1232          1	// Sonar
	#define is_mpu6050         0	// Accelerometer / Gyroscope (NOTE* I2C address conflicts with RTC if not manually changed) (much better supported on Ishield)
	#define is_ms5803          1	// Pressure Sensor
	#define is_sht31d          1	// Temperature / Humidity
	#define is_tsl2561         0	// Lux Sensor [cannot be used with AS726X or AS7265X]
	#define is_tsl2591         1	// Lux Sensor
	#define is_zxgesturesensor 1	// ZX_Distance Sensor
	#define is_button 		   1	// 1 to enable button
#endif
#if is_sapflow == 1
	#define is_lora           1      // enable LoRa
	#define is_rtc            1
	#define is_sd             1
	#if hub_node_type == 0       // if is hub
		#define is_ethernet   1
		#define is_pushingbox 1
	#elif hub_node_type == 1     // if is node
		#define num_analog    2      // two temperature sensors
		#define probe_type    0      // 0:TDM, 1: HRM
		#define is_sht31d     1      // Temperature / Humidity
		#define is_decagon    1      // Soil moisture
		#define heatpulse     2500   // For HRM probe heat pulse (e.g 2500:2.5 sec)
		#define senddelay     60000  // send data every 1 min
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

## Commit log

2019-02-24 Added Fusion360 files
    [Flat disk v1.f3d, FlatDisk_fixed.stl, Medium Dome Disk v1.f3d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]
2019-04-16 Reorganized documents
    [Flat disk v1.f3d, FlatDisk_fixed.stl, Medium Dome Disk v1.f3d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]
2019-04-16 Removed spaces from file names
    [FlatDisk_fixed.stl, Flat_Disk_v1.f3d, MediumDomeDisk_fixed.stl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]
2019-04-18 Create Material_List
2019-05-10 Added final prototype's Fusion360 file
    [Final-Printed-Prototype v1.f3d]
